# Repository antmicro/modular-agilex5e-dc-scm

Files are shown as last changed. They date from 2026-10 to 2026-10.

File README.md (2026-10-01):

# Agilex 5 DC-SCM Carrier Board



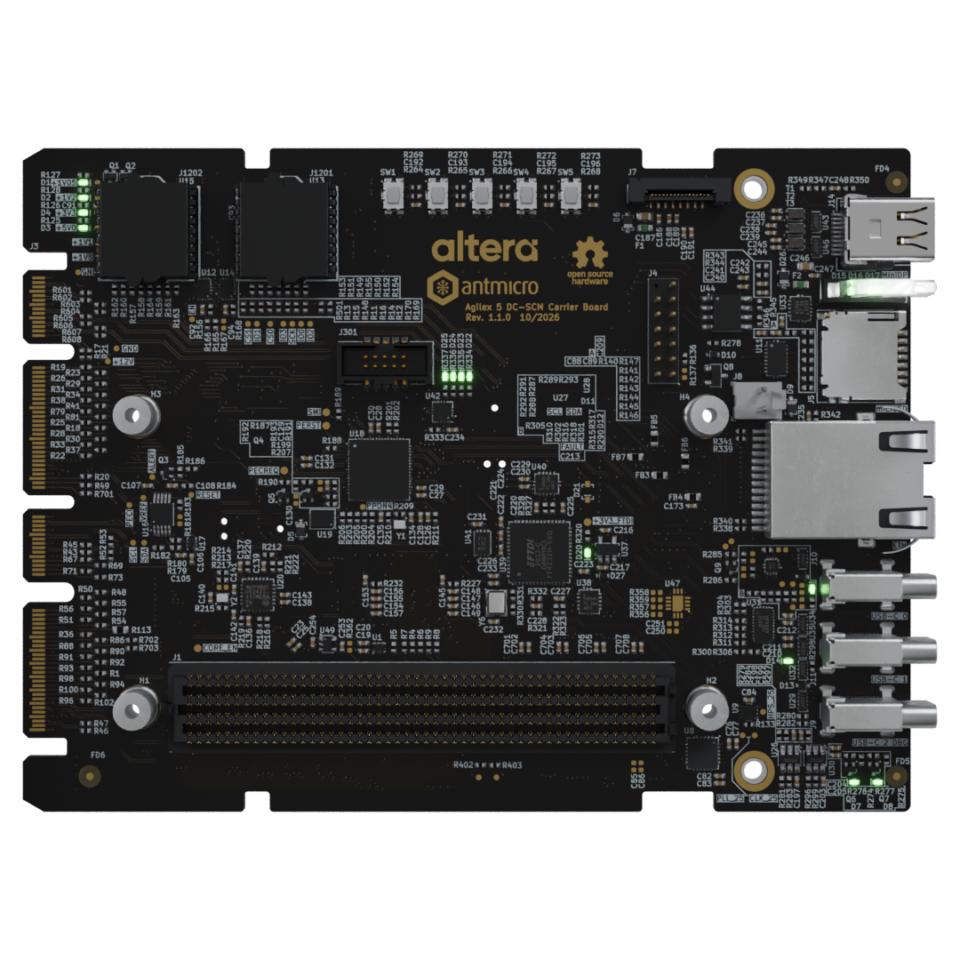
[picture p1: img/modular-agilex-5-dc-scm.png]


## Overview

This repository contains design files for a DC-SCM compliant Agilex 5 Modular DC-SCM Carrier Board that supports the [Critical Link MitySOM-A5E Mini](https://www.criticallink.com/product/mitysom-a5e-mini/) System on Module based on the [Altera Agilex 5E](https://www.altera.com/products/fpga/agilex/5) SoC family.
The board follows the interface and mechanical outline described in the 2.1 revision of the [DC-SCM standard](https://drive.google.com/file/d/1-SdSQvSWy5pNN_kBiyztblxE4jdyUe9W/view) specified by the Open Compute Project community.

The PCB design files were prepared in [KiCad](https://www.kicad.org/) 10.x.

## Key features

* Compatible with Agilex 5E based SoMs
* DC-SCM 2.1 compatible
* 1 Gb Ethernet PHY (Microchip Technology KSZ9131RNXC)
* DisplayPort connector
* High Speed connector in RPi 5 standard
* uSD Card Connector
* USB-C 2.0 port connected to Agilex 5E based SoM via USB3320C-EZK-TR PHY
* USB-C 3.0 from HPM
* USB-C port with FTDI FT2232H for SoM debug and software integration
* 2x BIOS Flash
* Optional on-board TPM connector
* 120.4 x 90 mm (4.74 x 3.54 inch) PCB outline

## Project structure

The main directory contains KiCad PCB project files, the LICENSE, and this README, and the img directory contains graphics for this README.

## Licensing

This project is published under the [Apache-2.0](LICENSE) license.

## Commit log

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2026-06-25 [#99541] Create hierarchical schematic stub. Add MitySOM-A5E Mini and DC-SCM 2.1 PCB edge connector
    [altera-modular-agilex-5-dc-scm.kicad_pcb, altera-modular-agilex-5-dc-scm.kicad_sch, dc-scm-connector.kicad_sch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]
2026-06-26 [#99600] Implement USB debug connector with FTDI and level shifters
    [front-panel-usb.kicad_sch, ftdi.kicad_sch]
2026-06-26 [#99600] Implement USB 2.0 and 3.0 USB-C ports
    [front-panel-usb.kicad_sch]
2026-06-26 [#99642] Add KSZ9131RNX PHY. Add ETH RJ45 front panel connector
    [eth.kicad_sch, front-panel-eth.kicad_sch]
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2026-06-26 [#99600] Change USB 3.0 connector load switch to have active low EN, unify net naming
    [front-panel-usb.kicad_sch]
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2026-06-26 [#99603] Add netclass rule areas to USB Controller schematic
    [usb-controller.kicad_sch]
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2026-06-26 [#99541] Import all hierarchical ports to root schematic sheet, start connecting sheets
    [altera-modular-agilex-5-dc-scm.kicad_sch, dc-scm-connector.kicad_sch, eth.kicad_sch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]
2026-06-26 [#99541] Fix page numbering of FTDI and USB Controller schematic sheets
    [altera-modular-agilex-5-dc-scm.kicad_sch, front-panel-usb.kicad_sch]
2026-06-26 [#99541] Fill out title block in FTDI schematic sheet
    [ftdi.kicad_sch]
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2026-06-29 [#99541] Connect ULPI, RGMII, SDIO and DisplayPort buses to MitySOM
    [altera-modular-agilex-5-dc-scm.kicad_sch, dc-scm-connector.kicad_sch, eth.kicad_sch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]
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2026-06-29 [#99727] Add ports on root schematic for ULPI
    [altera-modular-agilex-5-dc-scm.kicad_sch]
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2026-06-29 [#99727] Change ULPI bus type from input to bidirectional
    [altera-modular-agilex-5-dc-scm.kicad_sch, mitysom-a5e-mini.kicad_sch, ulpi-phy.kicad_sch]
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2026-06-29 [#99732] Rename TPM SPI buses, import them on root schematic
    [altera-modular-agilex-5-dc-scm.kicad_sch, tpm.kicad_sch]
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2026-06-29 Assign net classes for SDIO, PCIeREFCLK and ULPI
    [altera-modular-agilex-5-dc-scm.kicad_sch, mitysom-a5e-mini.kicad_sch, pcie-clk.kicad_sch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]
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2026-06-30 [#99852] Connect USB ID, VBUS detect, PPONx and OCIxB signals
    [altera-modular-agilex-5-dc-scm.kicad_sch, front-panel-usb.kicad_sch, ulpi-phy.kicad_sch]
2026-06-30 [#99867] Connect PCIe, DisplayPort and USB SS to GTS 1A transciver
    [mitysom-a5e-mini.kicad_sch]
2026-06-30 [#99647] Replace chokes on DisplayPort lines
    [front-panel-dp.kicad_sch]
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2026-07-01 [#99871] Rename PCIe CLK schematic sheet to CLK
    [altera-modular-agilex-5-dc-scm.kicad_sch, clk.kicad_sch]
2026-07-01 [#99871] Import ports from CLK sheet to root schematic
    [altera-modular-agilex-5-dc-scm.kicad_sch]
2026-07-01 [#99732] Fix TMP connection - connect via MUX to SPI and QSPI from DC-SCM
    [altera-modular-agilex-5-dc-scm.kicad_sch, tpm.kicad_sch]
2026-07-01 [#99974] Import DC-SCM ports on root schematic, start connecting them to other blocks
    [altera-modular-agilex-5-dc-scm.kicad_sch, power.kicad_sch]
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2026-07-02 [#100060] Move high speed connector to separate schematic sheet, connect it to SoM
    [altera-modular-agilex-5-dc-scm.kicad_sch, clk.kicad_sch, hs-connector.kicad_sch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]
2026-07-02 [#100060] Fix SoM DP and PCIe bus naming
    [altera-modular-agilex-5-dc-scm.kicad_sch, dc-scm-connector.kicad_sch, eth.kicad_sch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]
2026-07-02 [#100060] Replace high speed connector
    [hs-connector.kicad_sch]
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2026-07-03 [#100092] Connect eSPI to MitySOM. Supply 6A and 6B bank with 1V8
    [mitysom-a5e-mini.kicad_sch]
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2026-07-03 [#99769] Fix BIOS not having a hierarchical label to be connected to SoM
    [altera-modular-agilex-5-dc-scm.kicad_sch, bios.kicad_sch]
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2026-07-03 [#99649] Fix HS connector rule area, add DP AUX, HPD and CONFIG pins to DP bus, connect most signals on root schematic
    [altera-modular-agilex-5-dc-scm.kicad_sch, front-panel-dp.kicad_sch, hs-connector.kicad_sch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]
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2026-07-06 [#100282] Improve schematic readability - fix overlaping graphics, unify bus graphical style
    [bios.kicad_sch, clk.kicad_sch, dc-scm-connector.kicad_sch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]
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2026-07-06 [#100282] Swap TMP default from QSPI to SPI, add level shifter for PECI I2C bus, connect user button
    [altera-modular-agilex-5-dc-scm.kicad_sch, misc.kicad_sch, mitysom-config.kicad_sch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]
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2026-07-06 [#100282] Move AUX, HPD, CONFIG and AUX_DRV to separate DP_CTRL bus, connect HS connector remaining DP signals
    [altera-modular-agilex-5-dc-scm.kicad_sch, front-panel-dp.kicad_sch, hs-connector.kicad_sch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]
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2026-07-07 [#100282] Connect ETH PHY reset to SOM
    [altera-modular-agilex-5-dc-scm.kicad_sch, eth.kicad_sch, mitysom-hps.kicad_sch]
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2026-07-07 [#100282] Fix overlaping graphics, add schematic sheet names on them
    [dc-scm-connector.kicad_sch, eth.kicad_sch, front-panel-dp.kicad_sch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]
2026-07-07 [#100282] Add 0R to PECI RESET signal
    [peci.kicad_sch]
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2026-07-07 [#100282] Add missing PWR_FLAG
    [mitysom-power.kicad_sch]
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2026-07-08 [#100501] Add optional pullup for PECI address pin, add note about its address and translator having internal pullups
    [dc-scm-connector.kicad_sch, peci.kicad_sch]
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2026-07-08 [#100501] Change TMP MUX with the same one as used for BIOS MUX, fix CS connection
    [tpm.kicad_sch]
2026-07-08 [#100501] Add optionall pullup to HVIO_ENABLE, to enable power section without SOM
    [power.kicad_sch]
2026-07-08 [#100501] Change BIOS from BGA to SOIC, add series termination resistors, connect BIOS_RST signal to FPGA
    [altera-modular-agilex-5-dc-scm.kicad_sch, bios.kicad_sch, mitysom-hvio.kicad_sch]
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2026-07-08 [#100282] Add missing schematic sheet names and align them all
    [bios.kicad_sch, clk.kicad_sch, dc-scm-connector.kicad_sch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]
2026-07-09 [#100501] Replace 50R resistors with 49R9 in LTPI bias circuit
    [ltpi_bias.kicad_sch]
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2026-07-09 [#100501] Gate GbE_PHY_RESET with COLD_RESET signal, to reset ETH PHY
    [altera-modular-agilex-5-dc-scm.kicad_sch, eth.kicad_sch, mitysom-config.kicad_sch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]
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2026-07-09 [#100501] Fix USB hub and USB controller pin names
    [usb-controller.kicad_sch, usb-hub.kicad_sch]
2026-07-09 [#100501] Fix overlapping graphics in SOM connector symbol
    [mitysom-config.kicad_sch, mitysom-gts.kicad_sch]
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2026-07-09 [#100501] Fix DP.AUX +/- mixup
    [front-panel-dp.kicad_sch]
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2026-07-09 [#100501] Correct +3V3_HPM_FRU connection
    [power.kicad_sch]
2026-07-09 [#100501] Add Tag-Connect to JTAG and config EEPROM to FTDI, connect DC-SCM USB1 to USB controller
    [altera-modular-agilex-5-dc-scm.kicad_sch, dc-scm-connector.kicad_sch, front-panel-usb.kicad_sch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]
2026-07-10 [#100501] Add missing pullup resistors for USB controller, add Tag-Connect for its FLASH
    [usb-controller.kicad_sch]
2026-07-10 [#100501] Fix USB Hub strap option for non-removable ports
    [usb-hub.kicad_sch]
2026-07-10 [#100501] Add ferrite bead to CLK gen supply, change its decoupling from 1uF to 100nF, rename 20MHz bus to 25MHz
    [altera-modular-agilex-5-dc-scm.kicad_sch, clk.kicad_sch, mitysom-hsio.kicad_sch]
2026-07-10 [#100501] Change 1V2 and 1V05 DCDC inductors and add current draw assumptions
    [power.kicad_sch]
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2026-07-10 [#100501] Add test pints to DC-DC converters output and power indicator LEDs
    [power.kicad_sch]
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2026-07-10 [#100501] Pullup unused OCI from USB controller, fix 3V3 rail name on USB controller
    [altera-modular-agilex-5-dc-scm.kicad_sch, usb-controller.kicad_sch]
2026-07-10 [#100501] Fix DC-SCM I2C_16 SDA/SCL swap
    [dc-scm-connector.kicad_sch]
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2026-07-13 [#100687] Replace battery with LDO
    [mitysom-power.kicad_sch]
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2026-07-14 [#100764] Swap DC-SCM PCIe P/N for better PCB layout
    [mitysom-gts.kicad_sch]
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2026-07-14 [#100707] Move PCIe AC coupling capacitrs on the schematic, close to TX source, add 0Rs to DC-SCM PCIe
    [dc-scm-connector.kicad_sch, mitysom-gts.kicad_sch, usb-controller.kicad_sch]
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2026-07-14 [#100707] Place 0Rs on DC-SCM PCIe, start layout of clock signals, define more track widths and assign colors to power classes
    [clk.kicad_sch]
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2026-07-20 [#101136] Connect DC-SCM JTAG to HVIO. Expose HPS JTAG on debug connector
    [altera-modular-agilex-5-dc-scm.kicad_sch, ftdi.kicad_sch, mitysom-hps.kicad_sch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]
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2026-09-30 [#101095] Swap I2C on DC-SCM
    [dc-scm-connector.kicad_sch]
2026-09-30 [#101095] Swap I2C lines on HVIO
    [mitysom-hvio.kicad_sch]
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2026-09-30 [#101340] Clean up traces, reset silkscreen
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2026-09-30 [#101340] Update USB ILIM resistors to 4k7
    Re-use 4k7 resistors from other sheets. Resulting current ~1.45A
    [front-panel-usb.kicad_sch]
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2026-09-30 [#101340] Unify LEDs resistor values
    Front panel resistors @ 330Ohm, remaining ones 1kOhm
    [front-panel-usb.kicad_sch, ftdi.kicad_sch, power.kicad_sch]
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2026-09-30 [#101340] Clean co-layout DRC and fix trace widths, align silkscreen
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2026-09-30 [#101706] visualization: Update standoffs solder paste clearance for renders
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
